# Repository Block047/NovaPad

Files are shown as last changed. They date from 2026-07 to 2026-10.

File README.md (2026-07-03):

# NovaPad

NovaPad is a fully customizable and open sourced macropad that I had designed for fun in my spare time.

NovaPad was designed as a multi-purpose tool, allowing for it to aid in any task at hand.

## Features
Fully customizable:
 - EC11 Rotary Encoder Switch
 - 6 Keys
 - WS2812B RGB LED's for each key
 - 128x32 OLED screens 

## Housing
The housing is split into two parts, the top lid of the case, and the lower case itself.
The PCB is secured to the case using two M3 heated inserts vertically, and the lid is secured to the case using three horizontal self-tapping screws.

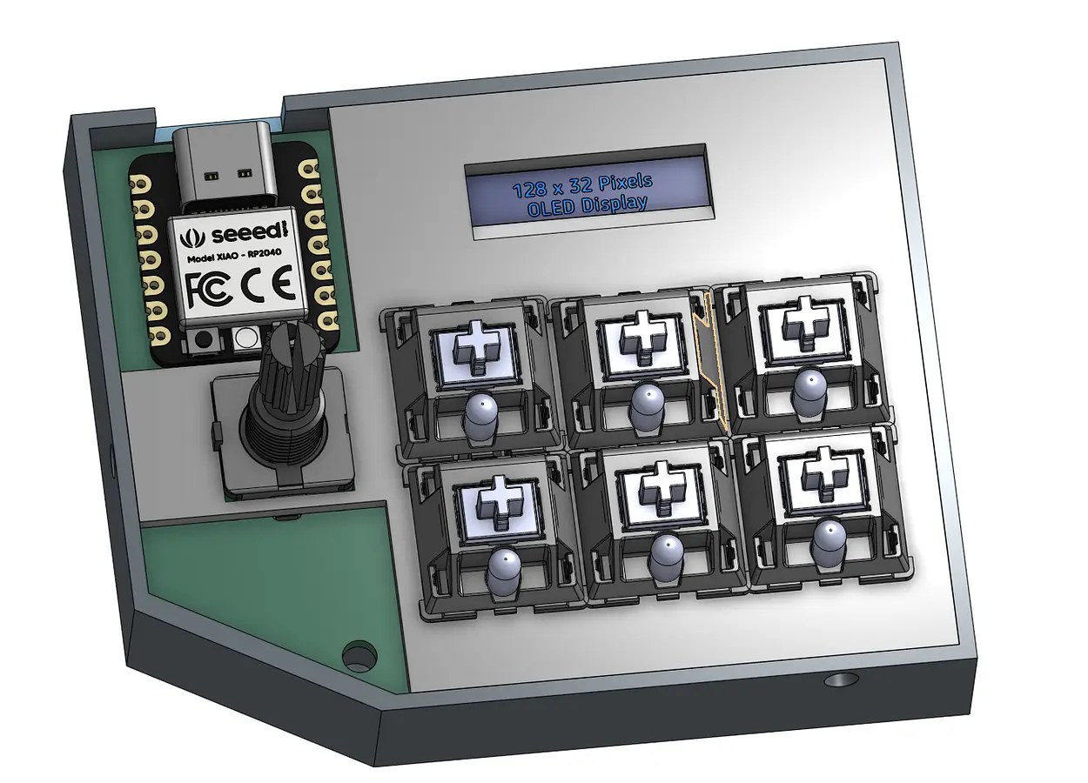
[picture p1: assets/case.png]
Case


Made in OnShape

## PCB
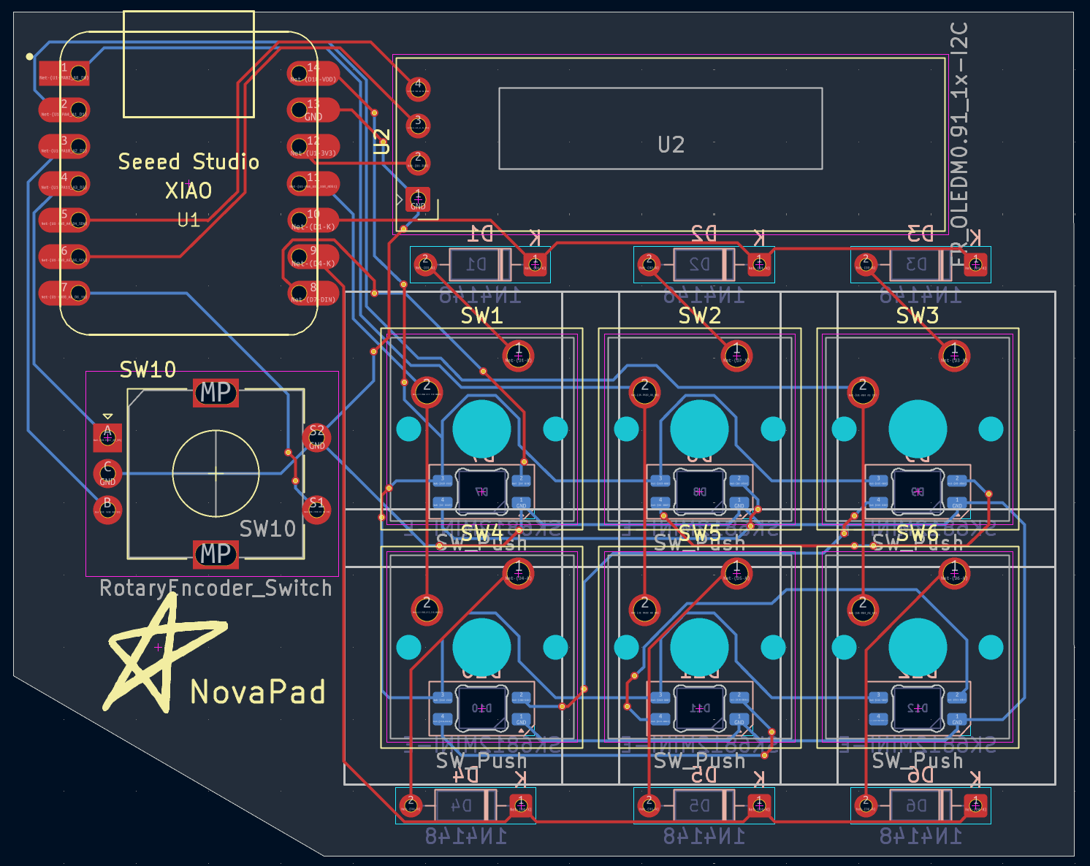
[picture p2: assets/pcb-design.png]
Design

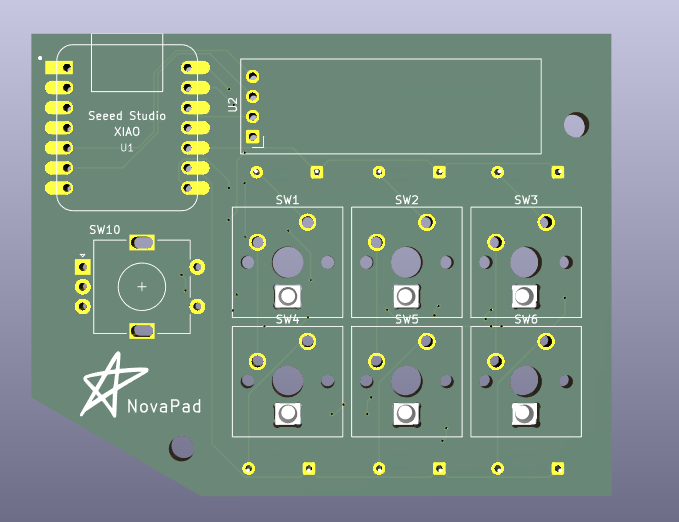
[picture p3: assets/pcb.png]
PCB


The PCB intergrates the various components included in the project, allowing them to communicate with one another, giving the keyboard its functionality.
Designing the PCB consisted of organizing the components in the positions that I wanted them in, and then drawing the trace lines, which took hours of work left untracked in hacktime (I was trying to use wakatime to track it, which ended up not working.)

## Schematic
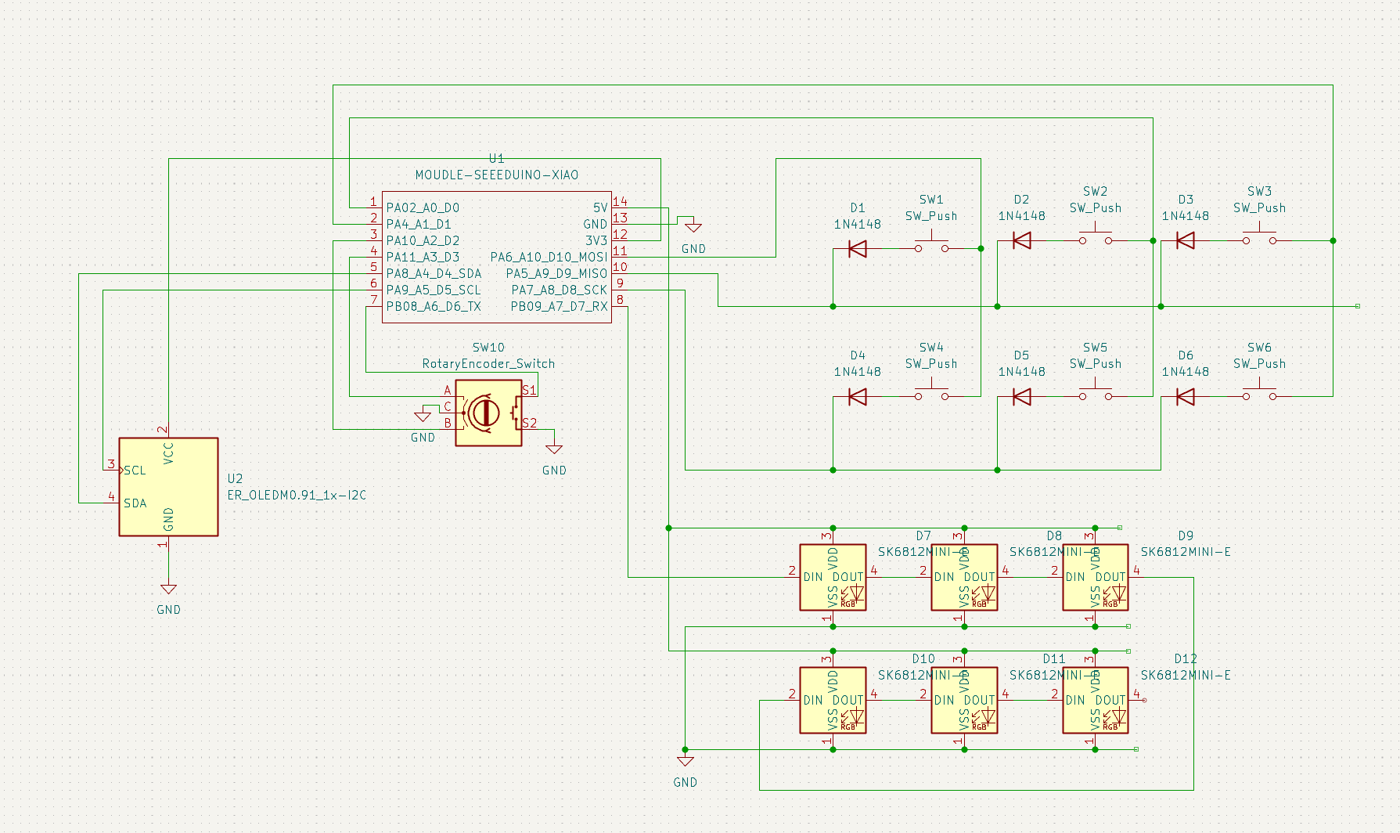
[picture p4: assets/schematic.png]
Schematic


The schematic had been the easiest part of the project, only specifying what connected to what.
The only decently difficult part of designing the schematic was figuring out where and how to get the footprints for the various components that KiCad didn't have, and figuring out how to wire the keyboard matrix.

## Firmware
This project uses KMK python code, running on the XIAO microcontroller provided by stardance flashed with CircuitPython.
The firmware leaves much for customization, the default functions only being a simple number pad with a volume knob, the OLED displaying "NovaPad".
This configuration was designed to be customized, giving the user flexability and functionality when needed.

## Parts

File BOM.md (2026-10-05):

# PCBs — bill of materials

<!-- Generated by Half Life from project cmuvmqs4z00lp01o9iztyflmu. Edits here are overwritten on the next sync. -->
<!-- Generated: 2026-10-05T20:33:29.766Z -->

> [!NOTE]
> This parts list is mirrored from [Half Life](https://halflife.hackclub.com). Editing it here will not change the platform's copy, and the next sync overwrites this file.

| Week | Tier | Parts funding |
| --- | --- | --- |
| Week 1 | Tier 1 | $30.00 |

| Part | What it's for | Qty | Unit | Total | Vendor |
| --- | --- | --- | --- | --- | --- |
| [PCB Printing](https://jlcpcb.com/) | Printing the PCB | 1 | $5.46 | $5.46 | [JLCPCB](https://jlcpcb.com/) |
| **Parts subtotal** | — | — | — | **$5.46** | — |
| **Tax & shipping** | — | — | — | **$0.00** | — |
| **Total** | — | — | — | **$5.46** | — |

$24.54 left of the tier's funding.

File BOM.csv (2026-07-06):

Item | Link | Provider | Quantity | Cost (Per Unit) | Total
PCB Printing | https://jlcpcb.com/ | JLCPCB | 5 (min) | N/A | $5.46
3D Printing Case | N/A | Friend | 1 | N/A | $0.00
MX-Style switches | https://hackpad.hackclub.com/parts | Stardance | 16 | $0.00 | $0.00
EC11 Rotary encoders | https://hackpad.hackclub.com/parts | Stardance | 2 | $0.00 | $0.00
0.91 inch OLED display | https://hackpad.hackclub.com/parts | Stardance | 1 | $0.00 | $0.00
White blank DSA keycaps | https://hackpad.hackclub.com/parts | Stardance | 16 | $0.00 | $0.00
SK6812 MINI-E LEDs | https://hackpad.hackclub.com/parts | Stardance | 20 | $0.00 | $0.00
M3x16mm screws | https://hackpad.hackclub.com/parts | Stardance | 6 | $0.00 | $0.00
M3x5mx4mm heatset inserts | https://hackpad.hackclub.com/parts | Stardance | 6 | $0.00 | $0.00
Pinecil | https://pine64.com/product/pinecil-smart-mini-portable-soldering-iron/ | Pine64 | 1 | $25.99 | $25.99
 |  |  |  |  | $31.45

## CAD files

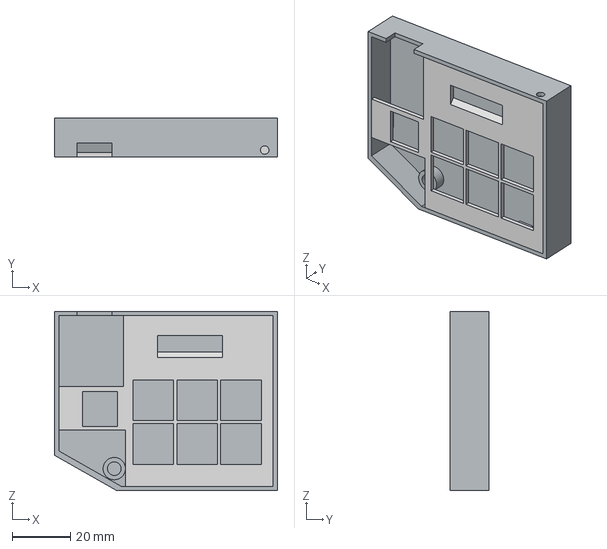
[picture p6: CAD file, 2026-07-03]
cad/NovaPad_Case_V1.step
76.8 x 13.4 x 61.8 mm

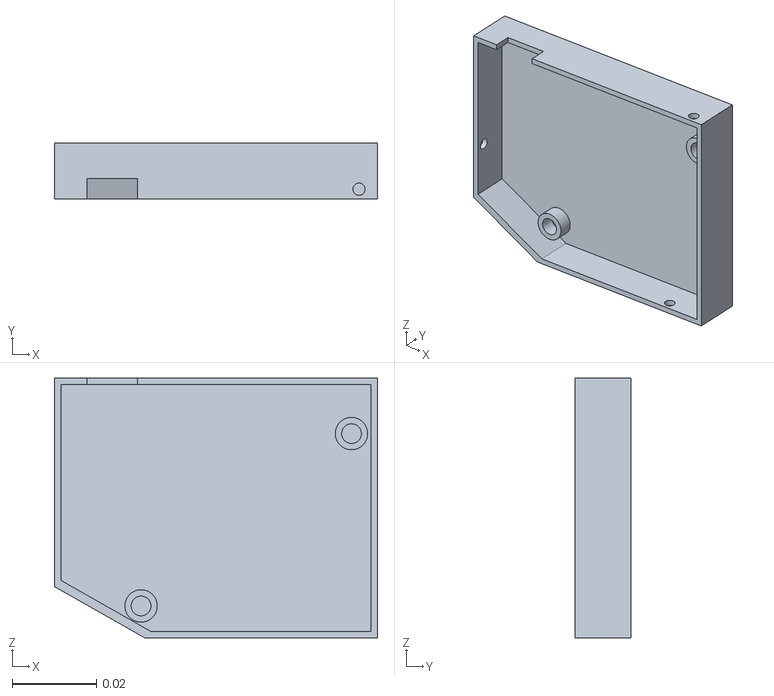
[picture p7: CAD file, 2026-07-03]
production/bottom_case.stl
0.0768 x 0.0134 x 0.0618

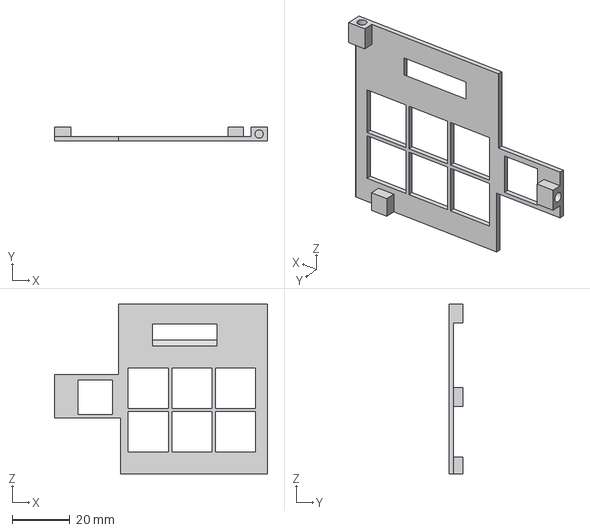
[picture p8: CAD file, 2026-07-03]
cad/top_plate.step
73.8 x 4.75 x 58.8 mm

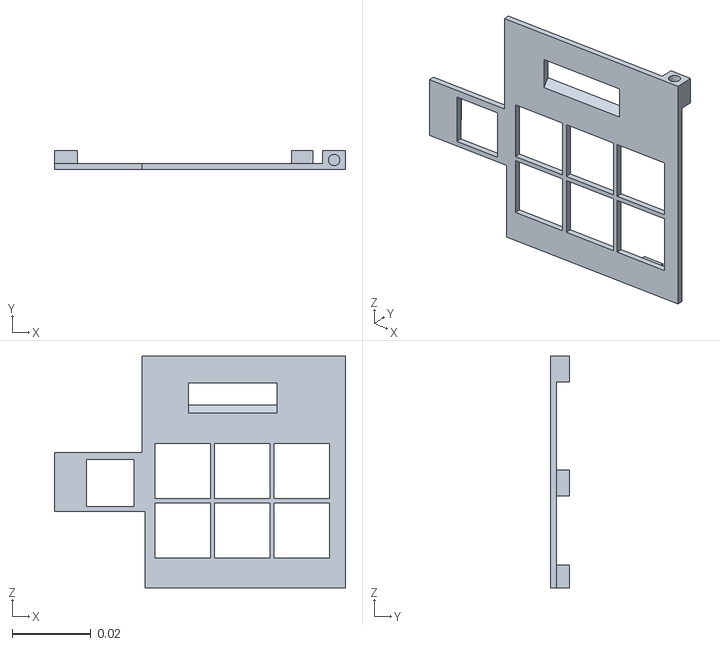
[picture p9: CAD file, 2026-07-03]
production/top_plate.stl
0.0738 x 0.00475 x 0.0588

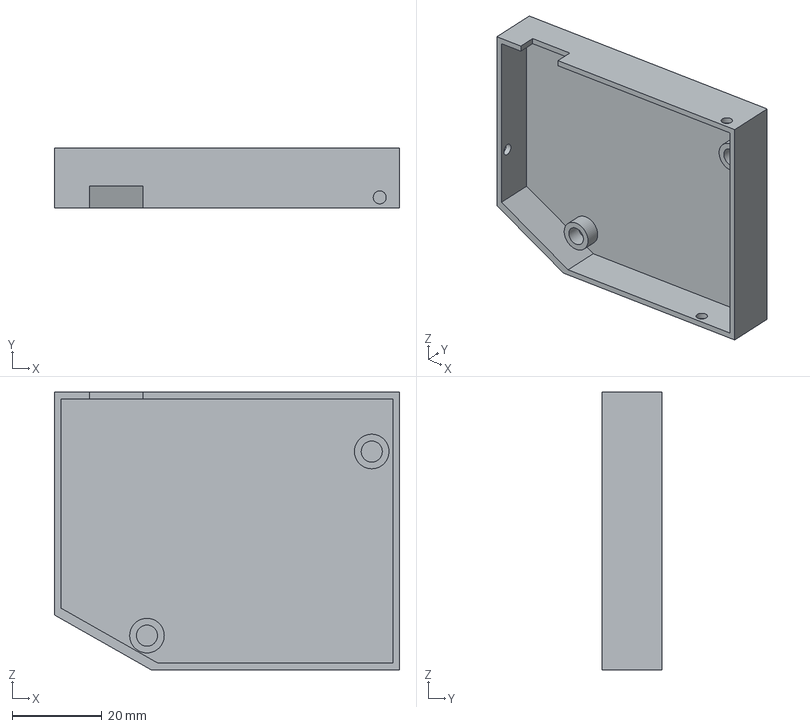
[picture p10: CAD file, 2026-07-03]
cad/bottom_case.step
76.8 x 13.4 x 61.8 mm

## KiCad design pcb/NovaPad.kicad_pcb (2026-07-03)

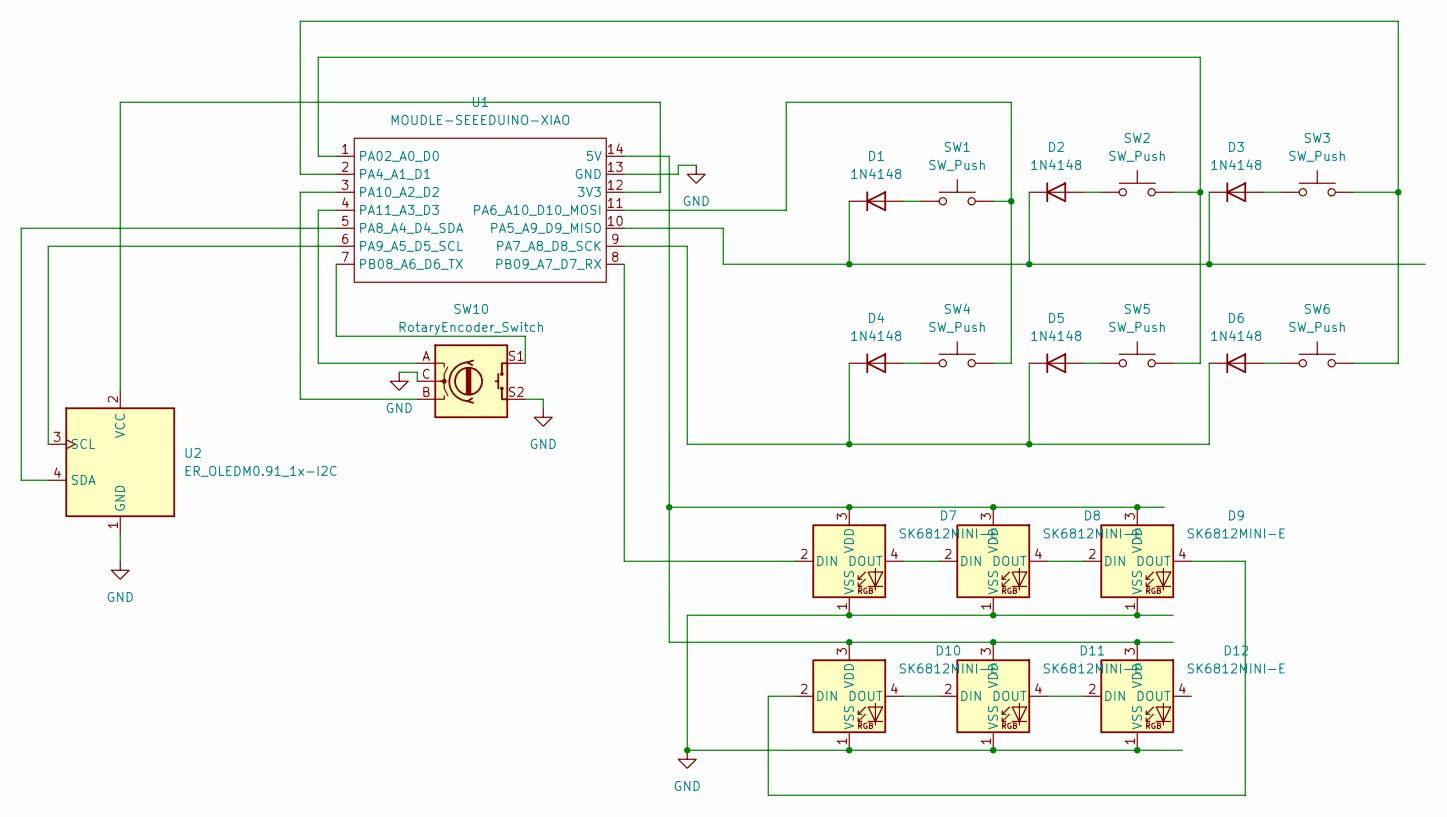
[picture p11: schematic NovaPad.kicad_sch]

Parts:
D1, D2, D3, D4, D5, D6: 1N4148; D_DO-35_SOD27_P7.62mm_Horizontal
D7, D8, D9, D10, D11, D12: SK6812MINI-E; LED_SK6812MINI-E_3.2x2.8mm_P1.5mm_ReverseMount
SW1, SW2, SW3, SW4, SW5, SW6: SW_Push; SW_Cherry_MX_1.00u_PCB
SW10: RotaryEncoder_Switch; RotaryEncoder_Alps_EC11E-Switch_Vertical_H20mm
U1: MOUDLE-SEEEDUINO-XIAO; XIAO-Generic-Hybrid-14P-2.54-21X17.8MM
U2: ER_OLEDM0.91_1x-I2C

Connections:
GND: D7.1 (VSS), D8.1 (VSS), D9.1 (VSS), D10.1 (VSS), D11.1 (VSS), D12.1 (VSS), SW10.C, SW10.S2, U1.13 (GND), U2.1 (GND)
unnamed: D1.2 (A), SW1.1
unnamed: D1.1 (K), D2.1 (K), D3.1 (K), U1.10 (PA5_A9_D9_MISO)
unnamed: D2.2 (A), SW2.1
unnamed: D3.2 (A), SW3.1
unnamed: D4.2 (A), SW4.1
unnamed: D4.1 (K), D5.1 (K), D6.1 (K), U1.9 (PA7_A8_D8_SCK)
unnamed: D5.2 (A), SW5.1
unnamed: D6.2 (A), SW6.1
unnamed: D7.2 (DIN), U1.8 (PB09_A7_D7_RX)
unnamed: D7.4 (DOUT), D8.2 (DIN)
unnamed: D8.4 (DOUT), D9.2 (DIN)
unnamed: D9.4 (DOUT), D10.2 (DIN)
unnamed: D10.4 (DOUT), D11.2 (DIN)
unnamed: D7.3 (VDD), D8.3 (VDD), D9.3 (VDD), D10.3 (VDD), D11.3 (VDD), D12.3 (VDD), U1.14 (5V)
unnamed: D11.4 (DOUT), D12.2 (DIN)
unnamed: U1.12 (3V3), U2.2 (VCC)
unnamed: SW2.2, SW5.2, U1.1 (PA02_A0_D0)
unnamed: SW3.2, SW6.2, U1.2 (PA4_A1_D1)
unnamed: SW1.2, SW4.2, U1.11 (PA6_A10_D10_MOSI)
unnamed: U1.5 (PA8_A4_D4_SDA), U2.4 (SDA)
unnamed: U1.6 (PA9_A5_D5_SCL), U2.3 (SCL)
unnamed: SW10.B, U1.3 (PA10_A2_D2)
unnamed: SW10.A, U1.4 (PA11_A3_D3)
unnamed: SW10.S1, U1.7 (PB08_A6_D6_TX)

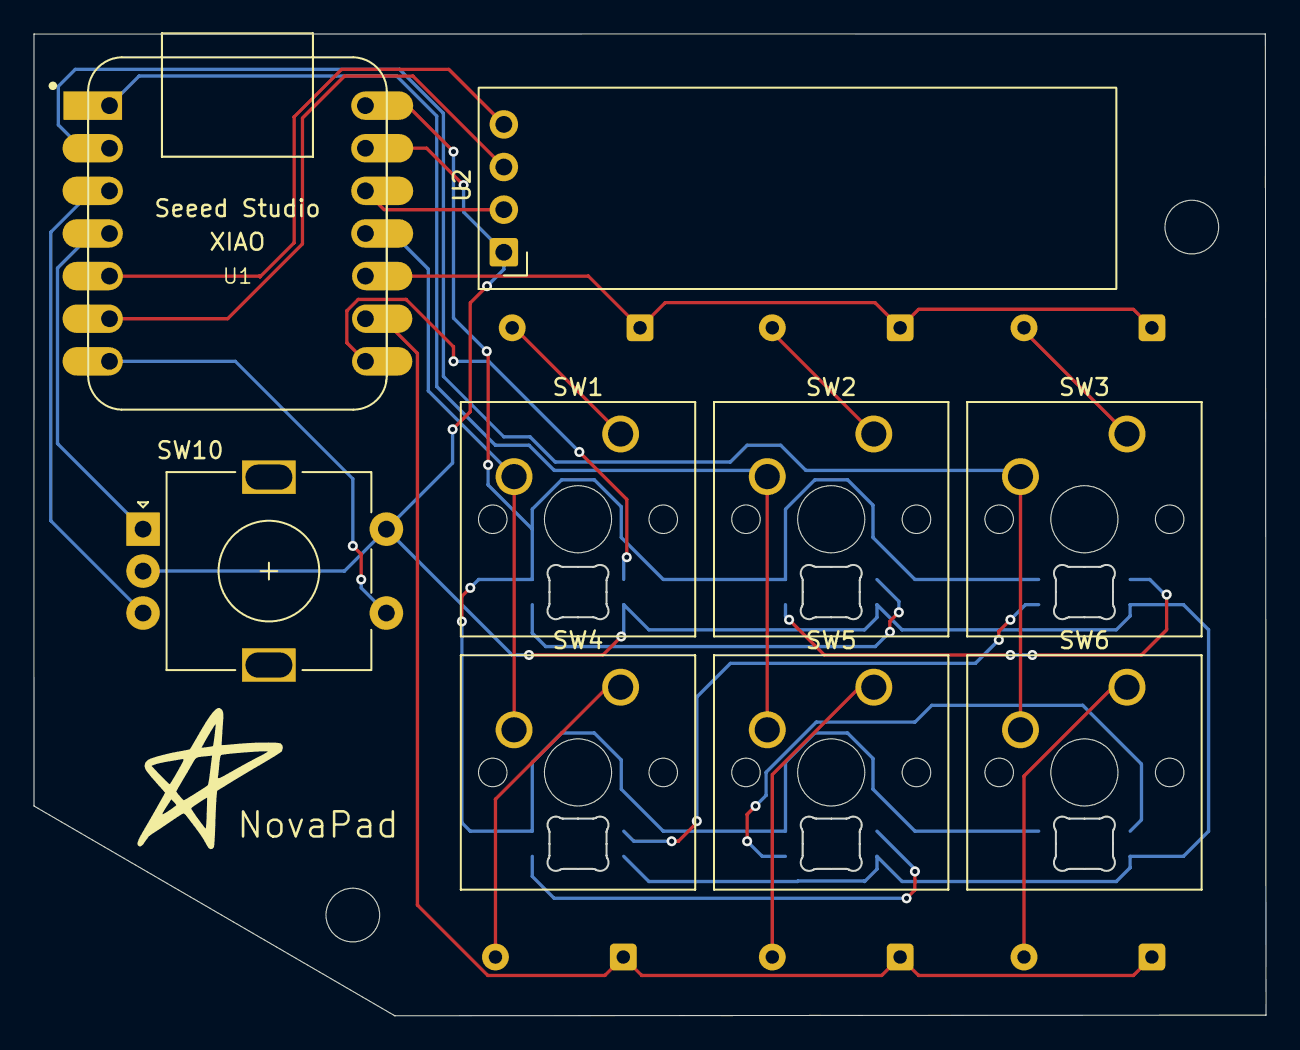
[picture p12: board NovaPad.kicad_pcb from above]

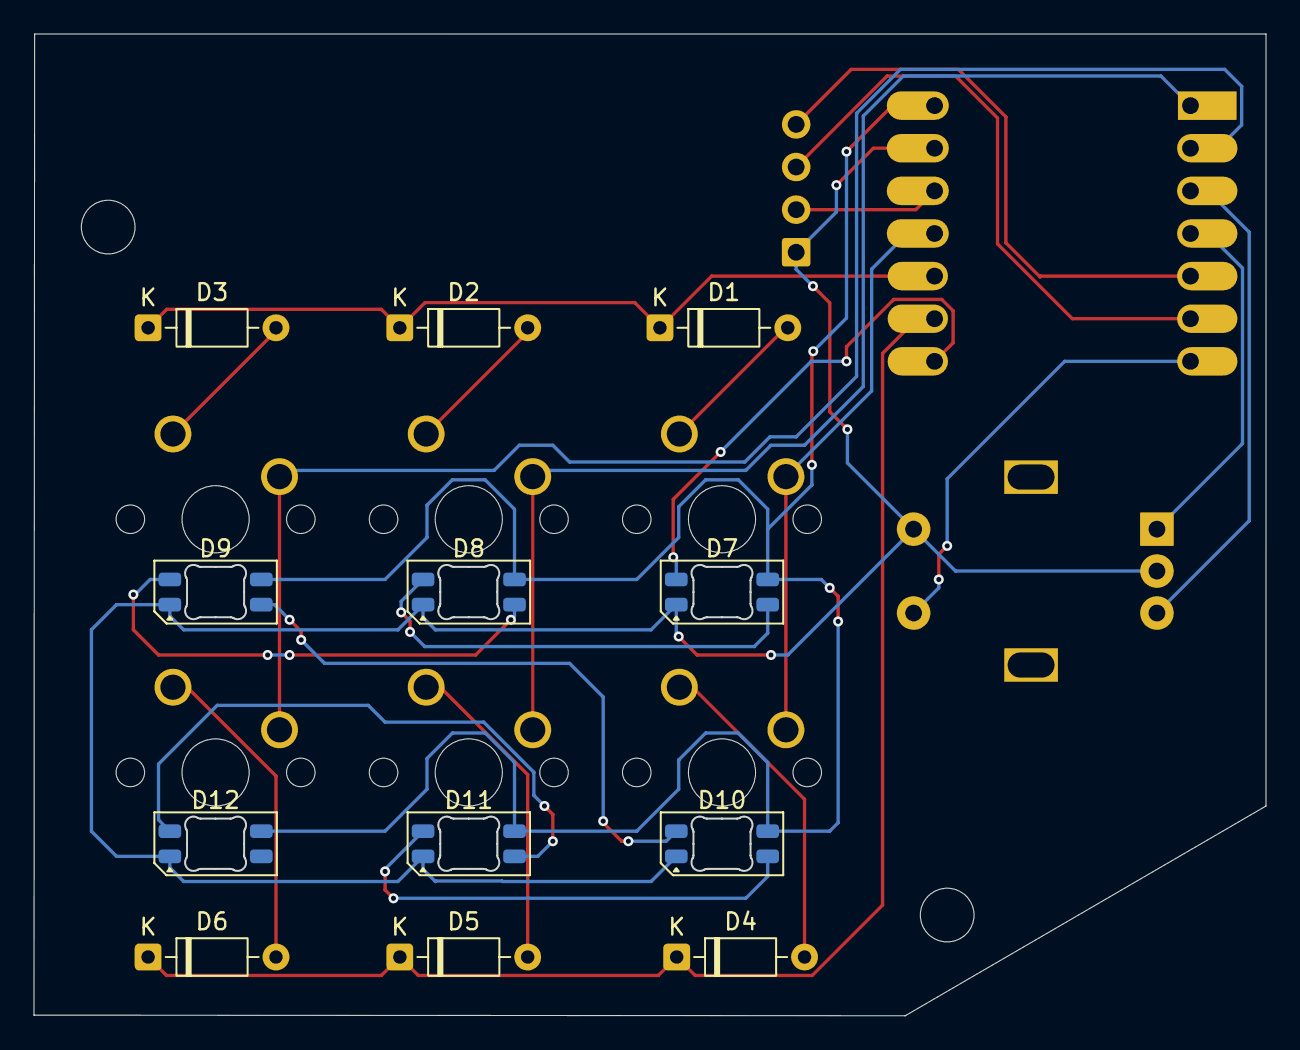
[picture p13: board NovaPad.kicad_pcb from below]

Board: 2 copper layers, 73.4 x 58.5 mm, 21 parts (12 on the bottom side), 25 nets.

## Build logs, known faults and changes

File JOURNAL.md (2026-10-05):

# PCBs — devlog

<!-- Generated by Half Life from project cmuvmqs4z00lp01o9iztyflmu. Edits here are overwritten on the next sync. -->
<!-- Generated: 1970-01-01T00:00:00.000Z -->

> [!NOTE]
> This devlog is mirrored from [Half Life](https://halflife.hackclub.com). Editing it here will not change the platform's copy, and the next sync overwrites this file.

| Week | Tier | Hours logged | Entries |
| --- | --- | --- | --- |
| Week 1 | Tier 1 | 0h | 0 |

_No entries logged yet._

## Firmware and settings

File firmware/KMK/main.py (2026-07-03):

import board
from kmk.kmk_keyboard import KMKKeyboard
from kmk.scanners import DiodeOrientation
from kmk.keys import KC
from kmk.modules.rgb import RGB
from kmk.modules.encoder import EncoderHandler

novapad = KMKKeyboard()

novapad.row_pins = (board.D9, board.D8)
novapad.col_pins = (board.D10, board.D0, board.D1)
novapad.diode_orientation = DiodeOrientation.COL2ROW

novapad.keymap = [
    [
        KC.N1, KC.N2, KC.N3,
        KC.N4, KC.N5, KC.N6,
    ]
]

encoder_handler = EncoderHandler()
encoder_handler.pins = (
    (board.D3,board.D2,board.D6,False),
)
encoder_handler.map = [
    ((KC.VOLD,KC.VOLU,KC.MUTE),),
]
novapad.modules.append(encoder_handler)

rgb = RGB(
    pixel_pin=board.D7,
    num_pixels=6,
    val_limit=100,
    hue_default=0,
    sat_default=100,
    val_default=50,
    animation_mode='static',
)
novapad.modules.append(rgb)

try:
    import busio
    import displayio
    import terminalio
    from adafruit_display_text import label
    from i2cdisplaybus import I2CDisplayBus
    import adafruit_displayio_ssd1306

    displayio.release_displays()
    i2c = busio.I2C(board.D5, board.D4)
    display_bus = I2CDisplayBus(i2c, device_address=0x3C)
    display = adafruit_displayio_ssd1306.SSD1306(display_bus, width=128,height=32)

    splash = displayio.Group()
    display.root_group = splash
    text_area = label.Label(terminalio.FONT, text="NovaPad", color = 0xFFFFFF, x=4, y=15)
    splash.append(text_area)
except Exception as e:
    print("OLED init fail: ", e)

if __name__ == '__main__':
    novapad.go()

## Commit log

2026-07-03 Started the README
    Added detailed description of NovaPad, its features, housing, and PCB design.
2026-07-03 Finished initial README file
    Updated README to clarify PCB functionality and added schematic section.
2026-10-05 Sync PCBs from Half Life
